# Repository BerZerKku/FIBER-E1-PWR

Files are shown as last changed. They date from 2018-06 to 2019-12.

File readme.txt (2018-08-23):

FIBER-E1-PWR
Плата питания преобразователя ОПТИКА - E1.

Плата предназначена для формирования напряжений 5 В из 220 В переменного и постоянного напряжения и 5 В из 48 В постоянного напряжения.
Предохранители по 220В 520.609 на ток 0.160А, по 48В 520.611 на ток 0.250А.
Держатели под предохранители 5х20 на панель 601.100 ESKA.

01v2

Код ПП: 3.140.811
Код ПП в сборе: 2.141.057

Замечания:
1. Маленькие отверстия под провода предохранителей.

Изменения:
1. Обновлено посадочное место VD5, VD6.
2. Добавлены реперные точки.
3. Посадочные места под L1,L2 и DA1 сделаны универсальными.

Стэк:
0.035 TOP
1.500
0.035 BOTTOM

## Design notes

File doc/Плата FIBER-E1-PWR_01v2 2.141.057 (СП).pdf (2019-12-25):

В разработке, напечатано: 04 октября 2019 г. 12:57:51, Кужбанов Михаил Евгеньевич
Поз. | Наименование | Корпус | Кол. | Поз. по Э3 | Примечание
| Документация
| Сборочный чертеж 2.141.057 | | 1
| Детали
1 | [3.140.811] Печатная плата FIBER-E1-PWR_01v2 | | 1
| Стандартные изделия
48 | [23545] Шайба плоская ф2,7, полиамид DIN125 | | 4
| Прочее
| Источники питания
2 | [AMEL5-5SEMAZ] Модульные источники питания AMEL5-5SEMAZ | DIP-5 | 1 | DA1 | Допустимые замены: [TMPS 03-105] Преобразовател ь напряжения TMPS 03-105 Traco
3 | [AM3T-4805SH35Z] Преобразователь напряжения AM3T-4805SH35Z Aimtec | DIP-14 | 1 | DA2 | Допустимые замены: [AM4T-4805SH35 -VZ] Преобразовател ь напряжения AM4T-4805SH35-VZ Aimtec
| Механика. Прочие
47 | [19569] Саморез 2,2 х 6,5 острый, полукругл. голова | | 4
| Конденсаторы
6 | [B32922C3224M] Конденсатор B32922C3224M 305V 0.22uF 20% Epcos | LEAD | 6 | C1, C5, C7, C12, C13, C16

2.141.057

1 | Лист | № докум | Подп. | Дата
Разраб. | Кужбанов М.Е. | | 01.06.2018 | Плата FIBER-E1-PWR_01v2 (Плата FIBER-E1-PWR_01v2 (для согласования)) | Лит. | Лист | Листов
Провер. | Вершинин А.С. | | 01.06.2018 | | | 1 | 5
Т.контр. | Бокова Т.И. | | 01.06.2018 | | Прософт-Системы
Н.контр. | Назаренко А.Н. | | 01.06.2018
Утв. | Чирков А.Г. | | 01.06.2018

7 | [DE1B3KX471KA4BN01 F] Конденсатор DE1B3KX471KA4BN01F Murata | LEAD-2 | 8 | C2-C4, C6, C10, C11, C14, C15 | Допустимые замены: [DE1B3KX471KA5 B] Конденсатор DE1B3KX471KA5B 470pF 250V 10% X1/Y1 Murata
8 | [LG063M4700BPF-304 0] Конденсатор LG063M4700BPF-3040 63V 4700uF 30*40 Yageo | LEAD | 2 | C8, C17
9 | [1206-X7R-50V-1uF-10%] [+] Чип-конденсатор 1206 X7R 50V 1uF 10% | 1206 | 2 | C9, C18
10 | [LH400M0470BPF-354 | LEAD | 1 | C19 | Допустимые
| 5] Конденсатор | | | | замены:
| LH400M0470BPF-3545 | | | | [LG400M0470BPF
| 400V 470uF 20% | | | | -3540]
| 35*45mm Yageo | | | | Конденсатор
| | | | | LG400M0470BPF-
| | | | | 3540 400V
| | | | | 470uF 20%
| | | | | 35*40mm
| | | | | Yageo;
| | | | | [LG450M0470BPF
| | | | | -3545]
| | | | | Конденсатор
| | | | | LG450M0470BPF-
| | | | | 3545 450V
| | | | | 470uF /35*45
| | | | | /105°C
| Предохранители,держатели предохранителей
16 | [JVR-20N391K] Варистор JVR-20N391K 390V 20mm 10% | LEAD-2 | 1 | RV1
| | | | | 2.141.057 | Лист 2 Изм
1 | Лист | № докум | Подп. | Дата

17 | [JVR-14N820K] Варистор JVR-14N820K 82V 14mm | LEAD-2 | 1 | RV3
18 | [P6SMB400A] Диод P6SMB400A SMB | SMB(DO -214 | 1 | VD3
19 | [SMBJ48A] Диод SMBJ48A | SMB(DO -214 | 1 | VD4
20 | [SM6T6V8A] Диод SM6T6V8A SMB STM | SMB(DO -214 | 2 | VD5, VD6
| Дроссели, фильтры, катушки индуктивности
25 | [7447471220] Индуктивность 7447471220 3.7A 22UH Wurth Electronics Inc. | LEAD-2 | 4 | L3-L6 | Допустимые замены: [TSL1112S-220K 2R9] Индуктивность TSL1112S-220K2 R9 2.9A 22uH 10% TDK
26 | [B82730U3162A020] Индуктивность B82730U3162A020 EPCOS | LEAD-4 | 2 | L1, L2 | Допустимые замены: [PLY10AN1521R6 R2B] Фильтр PLY10AN1521R6R 2B Murata
| Резисторы
29 | [SQM-5W-5.1K-5%] Резистор SQM-5W 5.1K 5% | LEAD-2 | 1 | R1
30 | [MFR-200JT-73-1M] Резистор MF-2 1M 5% | LEAD-2 | 4 | R2, R3, R5, R6
31 | [MF-2-510-5%] Резистор MF-2 510 5% | LEAD-2 | 4 | R4, R7, R8, R11
32 | [MF-2-5.1-5%] Резистор MF-2 5.1 5% | LEAD-2 | 2 | R9, R10
33 | [JNR15S070L] Резистор JNR15S070L терморезистор Joyin | LEAD-2 | 2 | TH1, TH2
| | | | 3 Изм
Лист | № докум | Подп. | Дата

| Диоды,светодиоды,супрессоры,стабилитроны
39 | [MB8S] Диод MB8S | SMD4 | 1 | VD1 | Допустимые замены: [B8S] Диодный мост B8S SMD4
| | | | | Galaxy
40 | [S3M] Диод S3M SMC | SMC(DO -214 | 3 | VD2, VD7, VD8
| Соединители
44 | [1806229] Ответная часть -GMSTB 2,5/ 2-GF-7,62, Номинальный ток: 12 А, Расчетное напряжение (III/2): 630 В, Полюсов: 2, Размер шага: 7,62 мм, Цвет: зеленый. | 2+2 | 1 | X1
45 | [1827868] Ответная часть -MC 1,5/ 2-GF-3,81, Номинальный ток: 8 А, Расчетное напряжение (III/2): 160 В, Полюсов: 2, Размер шага: 3,81 мм, Цвет: зеленый | 2+2 | 1 | X2
46 | [IDC-10M] Разъем IDC-10M | IDC10 | 1 | X3
| | | | 4 Изм
Лист | № докум | Подп. | Дата

Лист регистрации ревизий

№ ревизии | № замененных (измененных) страниц | Дата ревизии | Краткое содержание и причина внесения изменений | Примечание
0 | вновь | 01.06.18 | Вновь. | Егорова Елена Игоревна
1 | | 30.09.19 | Добавлены саморезы (поз. 47) для крепления разъемов Х1, Х2

2.141.057

5

Лист Изм. | Лист | № докум. | Подп. | Дата

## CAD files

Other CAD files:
doc/Плата FIBER-E1-PWR_01v2 2.141.057 (СБ).dwg
pcb/symbols/dip1016p5228x1780-5n.psm
pcb/symbols/fil_ply10.psm

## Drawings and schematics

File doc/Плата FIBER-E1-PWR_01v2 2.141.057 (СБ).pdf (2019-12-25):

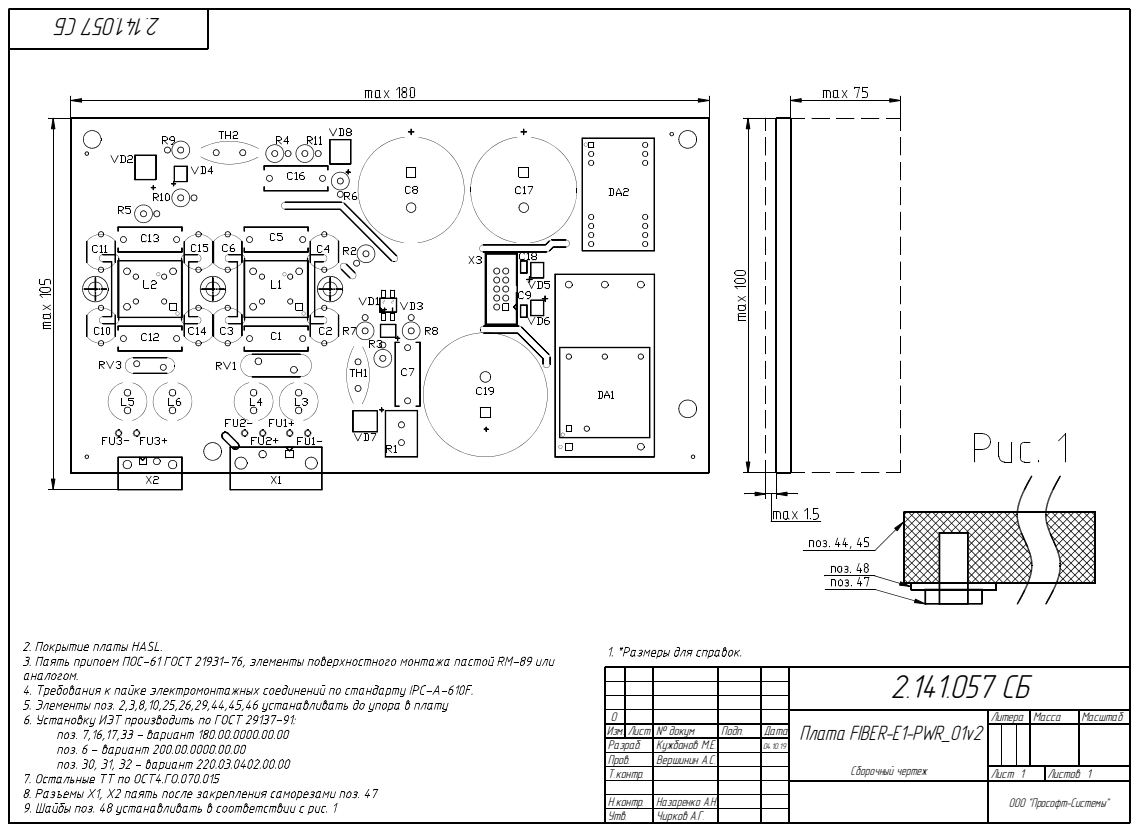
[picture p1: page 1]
Листов 1; Масса; Масштаб; Подп.; Дата; Утв.; Н.контр.; Т.контр.; Пров.; Разраб.; Изм. Лист; Чирков А.Г.; Назаренко А.Н.; Вершинин А.С.; Кужбанов М.Е.; № докум; Лист 1; Литера; Сборочный чертеж; Плата FIBER-E1-PWR_01v2

ООО "Прософт-Системы"

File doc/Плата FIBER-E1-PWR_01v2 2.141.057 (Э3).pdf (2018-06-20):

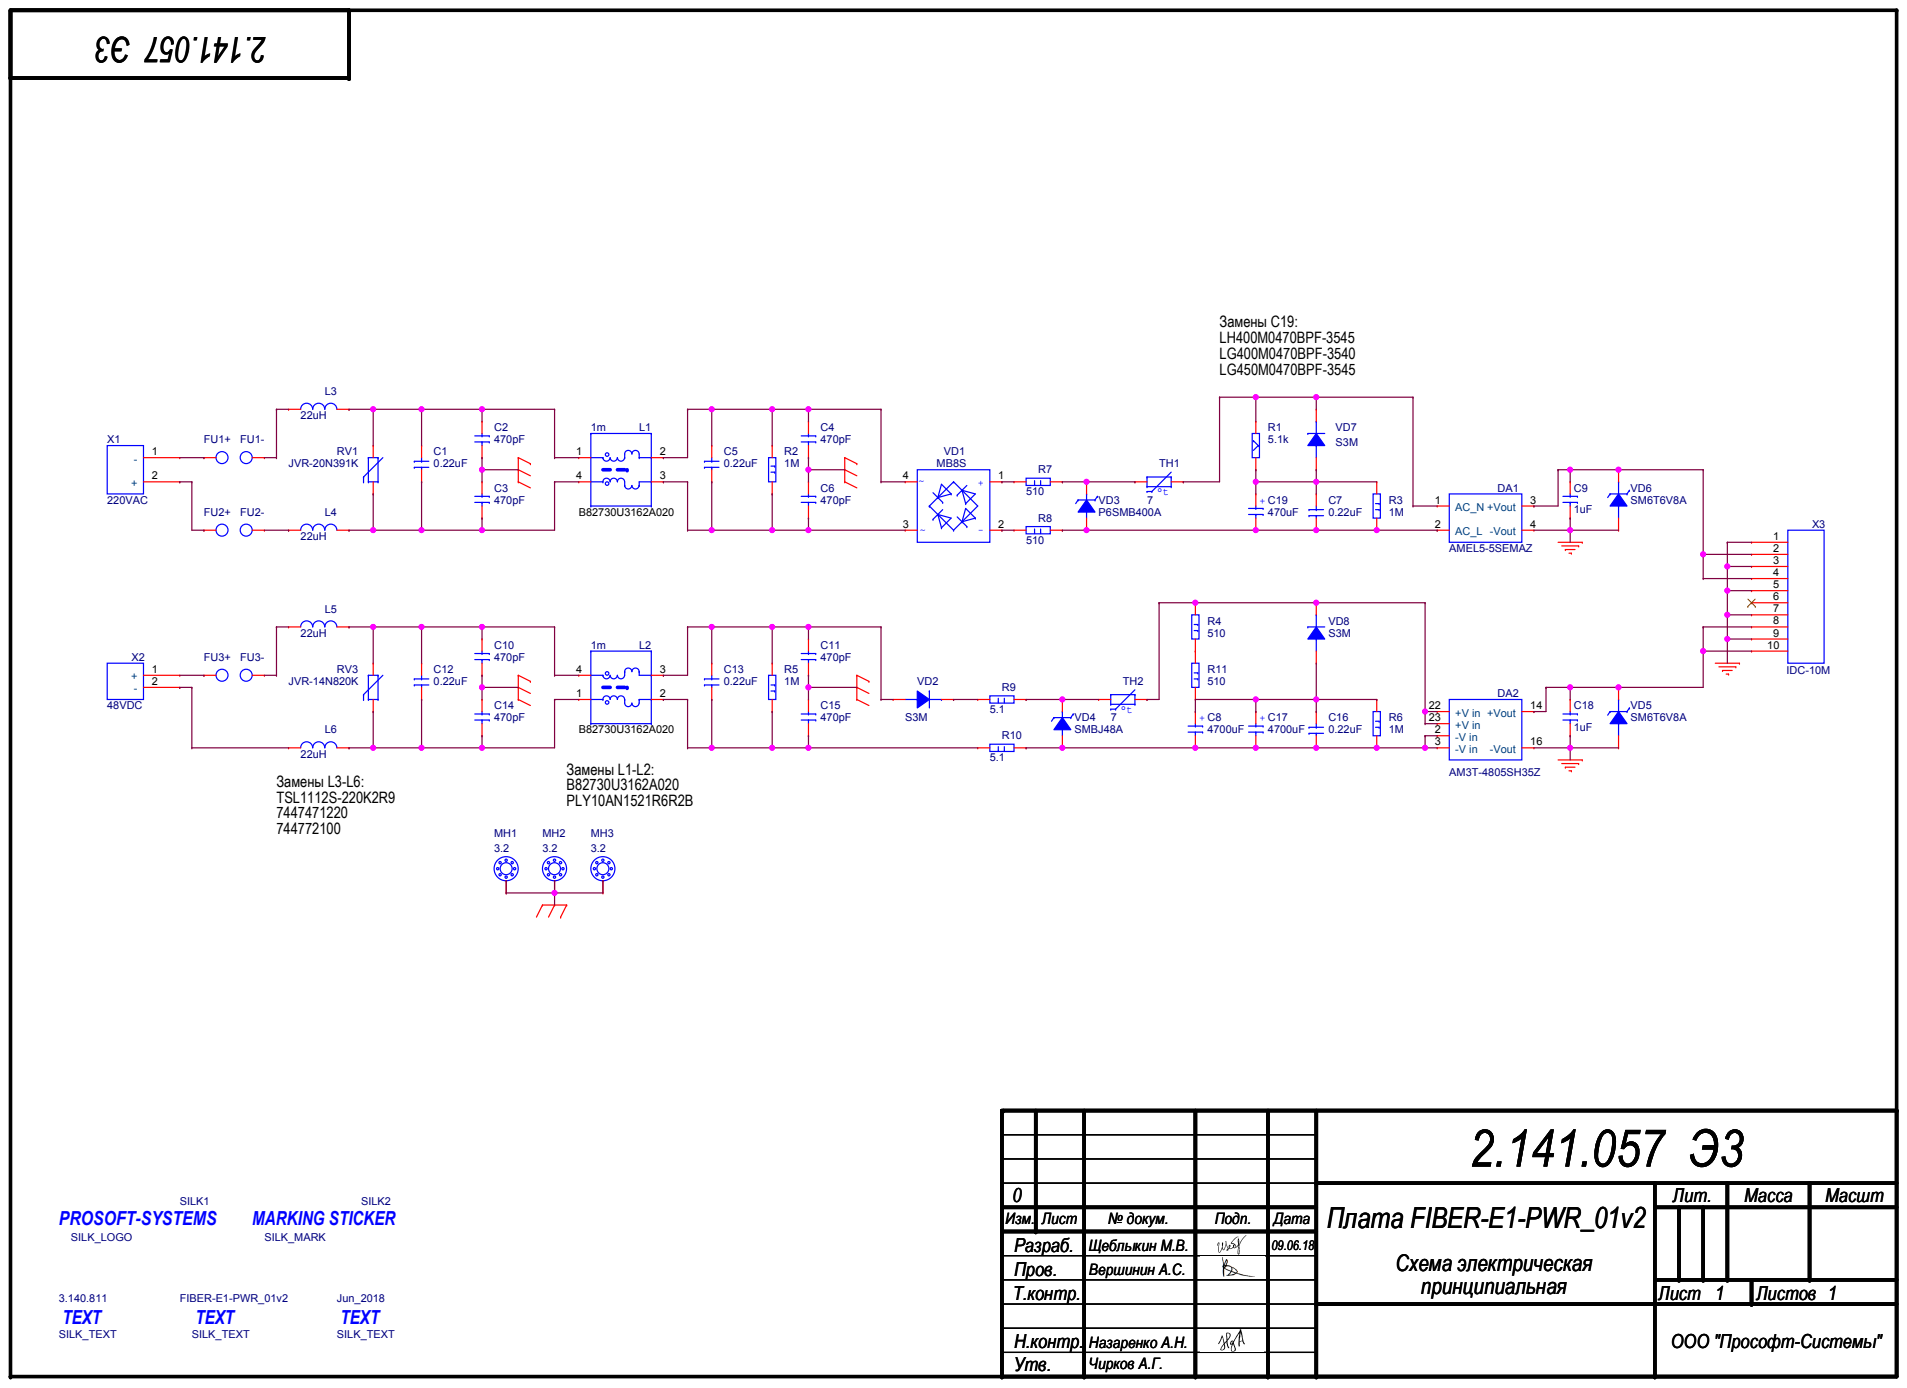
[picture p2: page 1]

0 | | | | | Плата FIBER-E1-PWR_01v2 Плата FIBER-E1-PWR_01v2 Плата FIBER-E1-PWR_01v2 Схема электрическая Схема электрическая Схема электрическая | Лит. | Масса Масса Масса | Масшт Масшт Масшт
Изм. Изм. Изм. | Лист Лист Лист | № докум. № докум. № докум. | Подп. Подп. Подп. | Дата Дата Дата
Разраб. Разраб. Разраб. | | Щеблыкин М.В. Щеблыкин М.В. Щеблыкин М.В. | | 09.06.18 09.06.18 09.06.18
Пров. Пров. Пров. | | Вершинин А.С. Вершинин А.С. Вершинин А.С.
принципиальная Т.контр. принципиальная Т.контр. принципиальная Т.контр. | Лист Лист Лист 1 1 1 1 1 1 | Листов Листов Листов

Н.контр. Н.контр. Н.контр. | Назаренко А.Н. Назаренко А.Н. Назаренко А.Н.
Утв. Утв. Утв. | Чирков А.Г. Чирков А.Г. Чирков А.Г.

ООО "Прософт-Системы" ООО "Прософт-Системы" ООО "Прософт-Системы"

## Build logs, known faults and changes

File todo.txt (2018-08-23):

1. Увеличить отверстия под предохранители до 2мм.

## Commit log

2016-02-01 Вновь.
2016-02-08 На схеме все элементы поставлены из БД.
    [FIBER-E1-PWR_01v0.DSN, FIBER-E1-PWR_01v0.brd]
2016-02-08 Заменены супрессоры P6SMB6.8A на SM6T6V8A. Исправлено подключение ИП DA3, была перепутана полярность на выходе.
    [FIBER-E1-PWR_01v0.DSN, FIBER-E1-PWR_01v0.brd]
2016-02-09 Добавлены отверстия для соединения с землей. Сделана предварительная разводка.
    [FIBER-E1-PWR_01v0.DSN, FIBER-E1-PWR_01v0.brd]
2016-02-09 Исправлены размеры платы. Пододвинуты разъемы.
    [FIBER-E1-PWR_01v0.brd]
2016-02-09 Добавлены отверстия крепления платы. Подправлены вырезы на плате.
    [FIBER-E1-PWR_01v0.DSN, FIBER-E1-PWR_01v0.brd]
2016-02-09 Убрана надпись о предохранителях.
    [FIBER-E1-PWR_01v0.DSN]
2016-02-16 Подвинуты разъемы.
    [FIBER-E1-PWR_01v0.brd]
2016-02-16 Расставлена шелкография. Вырезы на плате сделаны линиями по контуру.
    [FIBER-E1-PWR_01v0.DSN, FIBER-E1-PWR_01v0.brd]
2016-04-15 На плате сдвинуты крепежные отверстия.
    [FIBER-E1-PWR_01v0.brd]
2016-04-18 Заменен разъем питания 48В на шаг 3.81, чтобы отличался от 220В.
    [FIBER-E1-PWR_01v0.DSN, FIBER-E1-PWR_01v0.brd]
2016-05-06 Мелкие коррекции при подготовке герберов.
    [FIBER-E1-PWR_01v0.brd]
2016-05-19 В файл описания добавлена информация о предохранителях и их держателях.
2016-05-31 Добавлена документация на плату.
    [FIBER-E1-PWR_01v0.DSN, FIBER-E1-PWR_01v0.brd]
2016-05-31 СП rev.0 СБ rev.0
    Доделана документация на плату.
    [FIBER-E1-PWR_01v0.brd]
2016-06-14 СП изм. 1 / СБ изм. 1
    Для диодного моста на СБ добавлены обозначения выводов "+", "-" и "~". Для этого исправлен слой сборки на посадочном месте.
    [FIBER-E1-PWR_01v0.brd, sot250p700x270-4n.psm]
2016-10-11 Изменены названия файлов.
    [FIBER-E1-PWR_01v1.DSN, FIBER-E1-PWR_01v1.brd]
2016-10-11 Добавлены цепи заряда конденсаторов.
    [FIBER-E1-PWR_01v1.DSN, FIBER-E1-PWR_01v1.brd, PWR_220.DSN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]
2016-10-12 В цепи заряда конденсаторов по 48В параллельные резисторы заменены последовательными. Крепежные отверстия на земле изменены на прошитые переходными отверстиями. Медь в стэке изменена на 35 мкм.
    [FIBER-E1-PWR_01v1.DSN, FIBER-E1-PWR_01v1.brd, mtg720h320.psm]
2016-10-12 Переходные отверстия в CM и на крепежных отверстиях изменены на v800h300.
    [FIBER-E1-PWR_01v1.DSN, FIBER-E1-PWR_01v1.brd, mtg720h320.psm]
2016-10-12 Добавлены файлы заказа.
    [FIBER-E1-PWR_01v1 12.10.16.xls, art_param.txt, nc_param.txt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]
2016-10-13 Номинал резистора SQM-5W исправлен на 5.1кОм.
    [FIBER-E1-PWR_01v1.DSN, FIBER-E1-PWR_01v1.brd]
2016-10-13 Подготовлена документация на плату.
2016-12-06 Добавлены замечания от ЦМПП.
2018-04-12 СП изм.3 СБ изм.3 Изменения в СП: Использовать СБ изм.3. Изменения в СБ: В пункт 5 ТТ добавлена поз.63. В пункте 6 поз.57 устанавливать по варианту 220, как 59 и 61.
2018-06-09 Подготовлены файлы для новой платы.
    [FIBER-E1-PWR_01v1.DSN, FIBER-E1-PWR_01v2.DSN, FIBER-E1-PWR_01v2.brd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]
2018-06-14 Добавлены универсальные посдаочные места для L1,L2 и DA1.
    [FIBER-E1-PWR_01v2.DSN, FIBER-E1-PWR_01v2.brd]
2018-06-20 Добавлены схема, спецификация и фалы заказа. На плате добавлены реперные точки.
    [FIBER-E1-PWR_01v1 12.10.16.xls, FIBER-E1-PWR_01v2 20.06.18.xls, FIBER-E1-PWR_01v2.DSN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]
2018-06-22 Исправлен файл заказа (дата).
    [FIBER-E1-PWR_01v2 20.06.18.xls, FIBER-E1-PWR_01v2 22.06.18.xls]
2018-07-10 Доделана документация. На посадочном месте для дросселей дорисован слой сборки.
    [fil_ply10.psm]
2018-08-23 Маленькие отверстия под провода предохранителей.
2019-12-25 Добавлены саморезы для крепления разъемов.
    СП и СБ переделывал Миша и последний теперь сделан в NanoCAD.
    [Плата FIBER-E1-PWR_01v2 2.141.057 (СБ).dwg]
